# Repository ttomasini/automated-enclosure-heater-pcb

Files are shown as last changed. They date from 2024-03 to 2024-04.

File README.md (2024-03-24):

# Automated Heating System PCB for the Original Prusa Enclosure

## Introduction
This repo contains a PCB implementation of the Automated Heating System control unit for the Original Prusa Enclosure.

Find the schematics [here](doc/schematic.pdf).

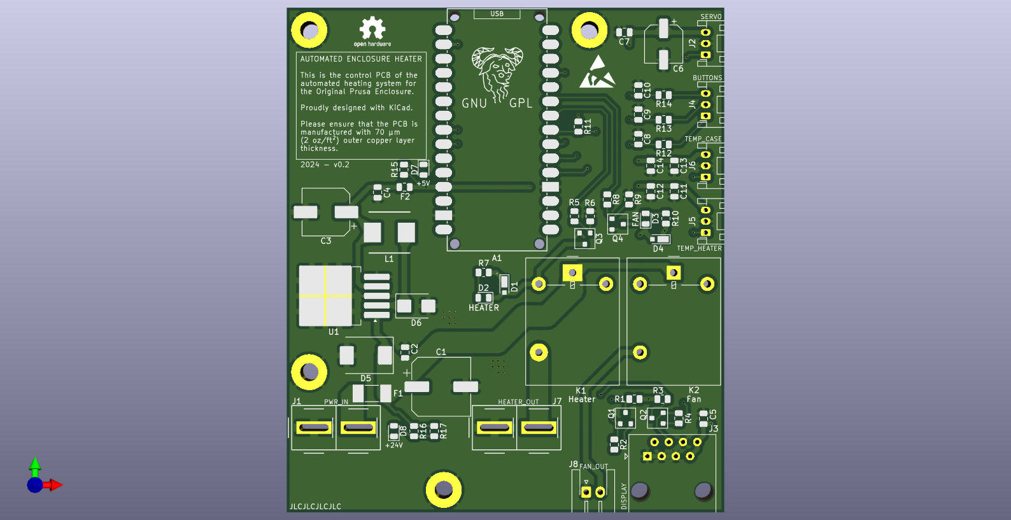
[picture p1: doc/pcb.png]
PCB

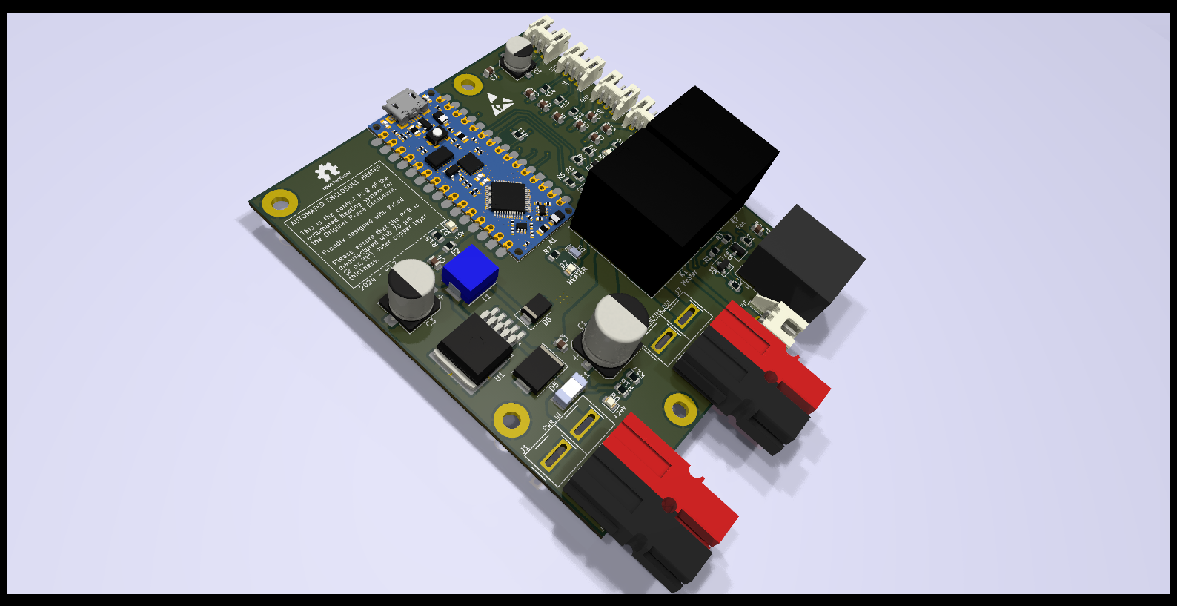
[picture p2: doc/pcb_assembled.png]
PCB assembled


## Manufacturing
Please ensure that the PCB is manufactured with 70 μm (2 oz/ft²) outer copper layer thickness.

## Credits
The original idea and the base principle of the schematic have been designed and published by Lars Knust ([@LarsKnust at Github](https://github.com/LarsKnust) / [@lars at printables.com](https://www.printables.com/@lars)).

Link to the model on Printables: https://www.printables.com/model/561491

This PCB has been proudly designed with KiCad.

## License
This repository is licensed under the GNU General Public License, Version 3. See [the LICENSE file](LICENSE) for more information.

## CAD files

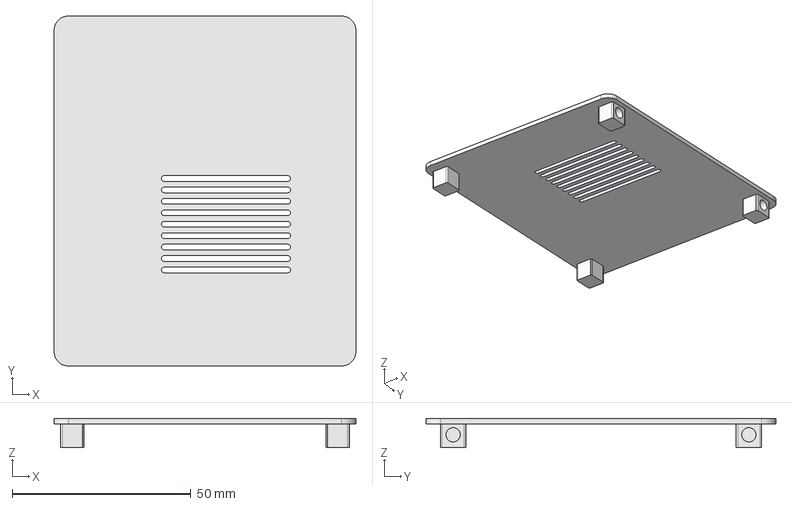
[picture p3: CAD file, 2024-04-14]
Case/Case-Lid.step
84.5 x 98.0 x 8.20 mm

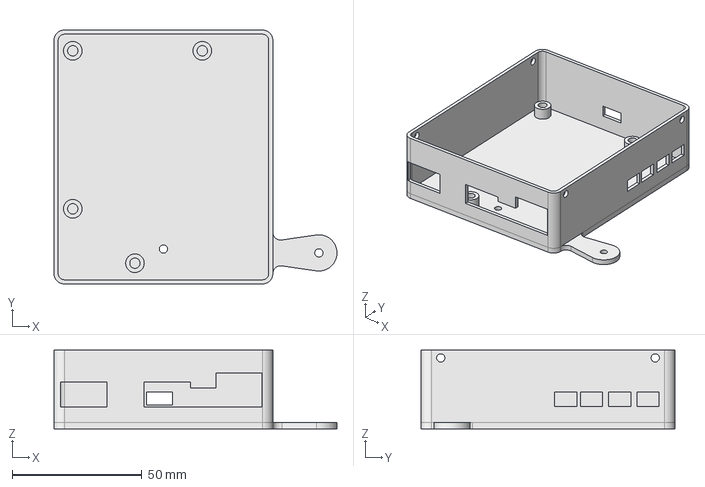
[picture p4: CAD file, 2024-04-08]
Case/Case-Body.step
109.2 x 98.0 x 30.4 mm

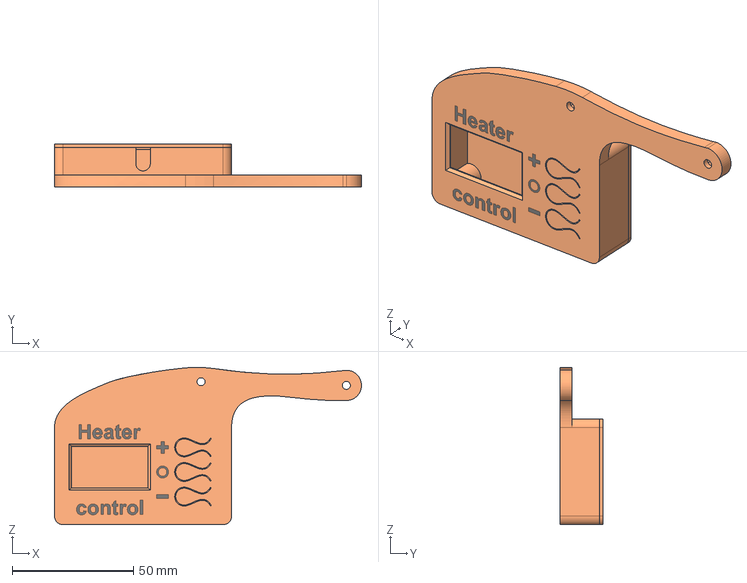
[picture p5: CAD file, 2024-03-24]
Case/Display_Case.step
126.8 x 17.8 x 65.0 mm

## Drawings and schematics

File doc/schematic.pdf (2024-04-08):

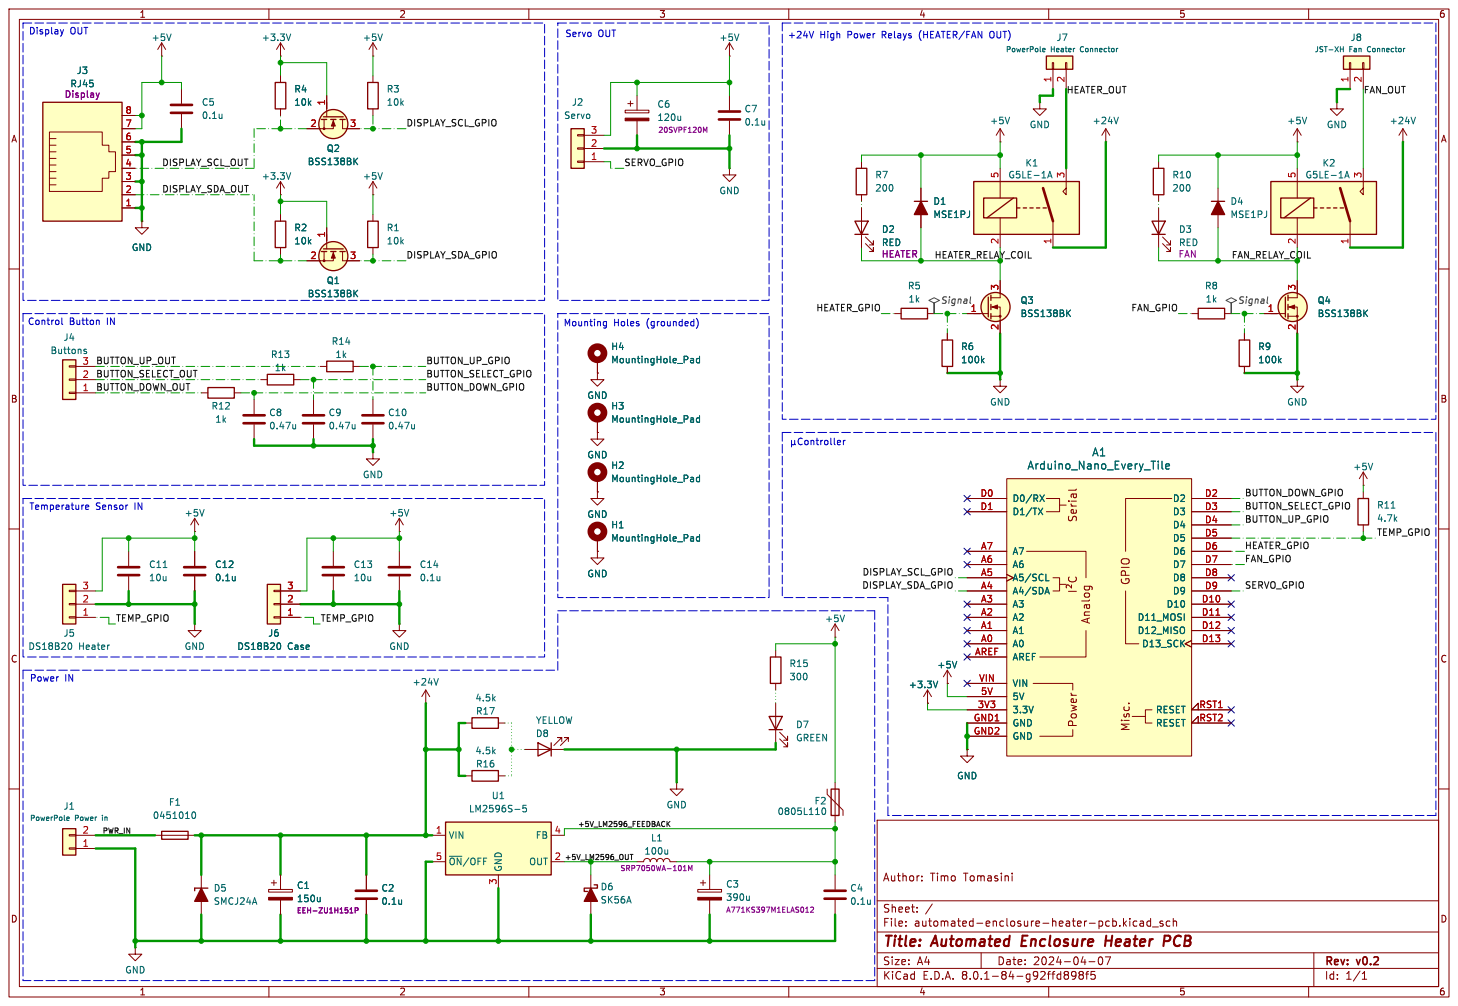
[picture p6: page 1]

Servo OUT Control Button IN

+24V High Power Relays (HEATER/FAN OUT)
J2 Servo R16

JST-XH Fan Connector 1

File: automated-enclosure-heater-pcb.kicad_sch Sheet: / Author: Timo Tomasini
Id: 1/1 Title: Automated Enclosure Heater PCB

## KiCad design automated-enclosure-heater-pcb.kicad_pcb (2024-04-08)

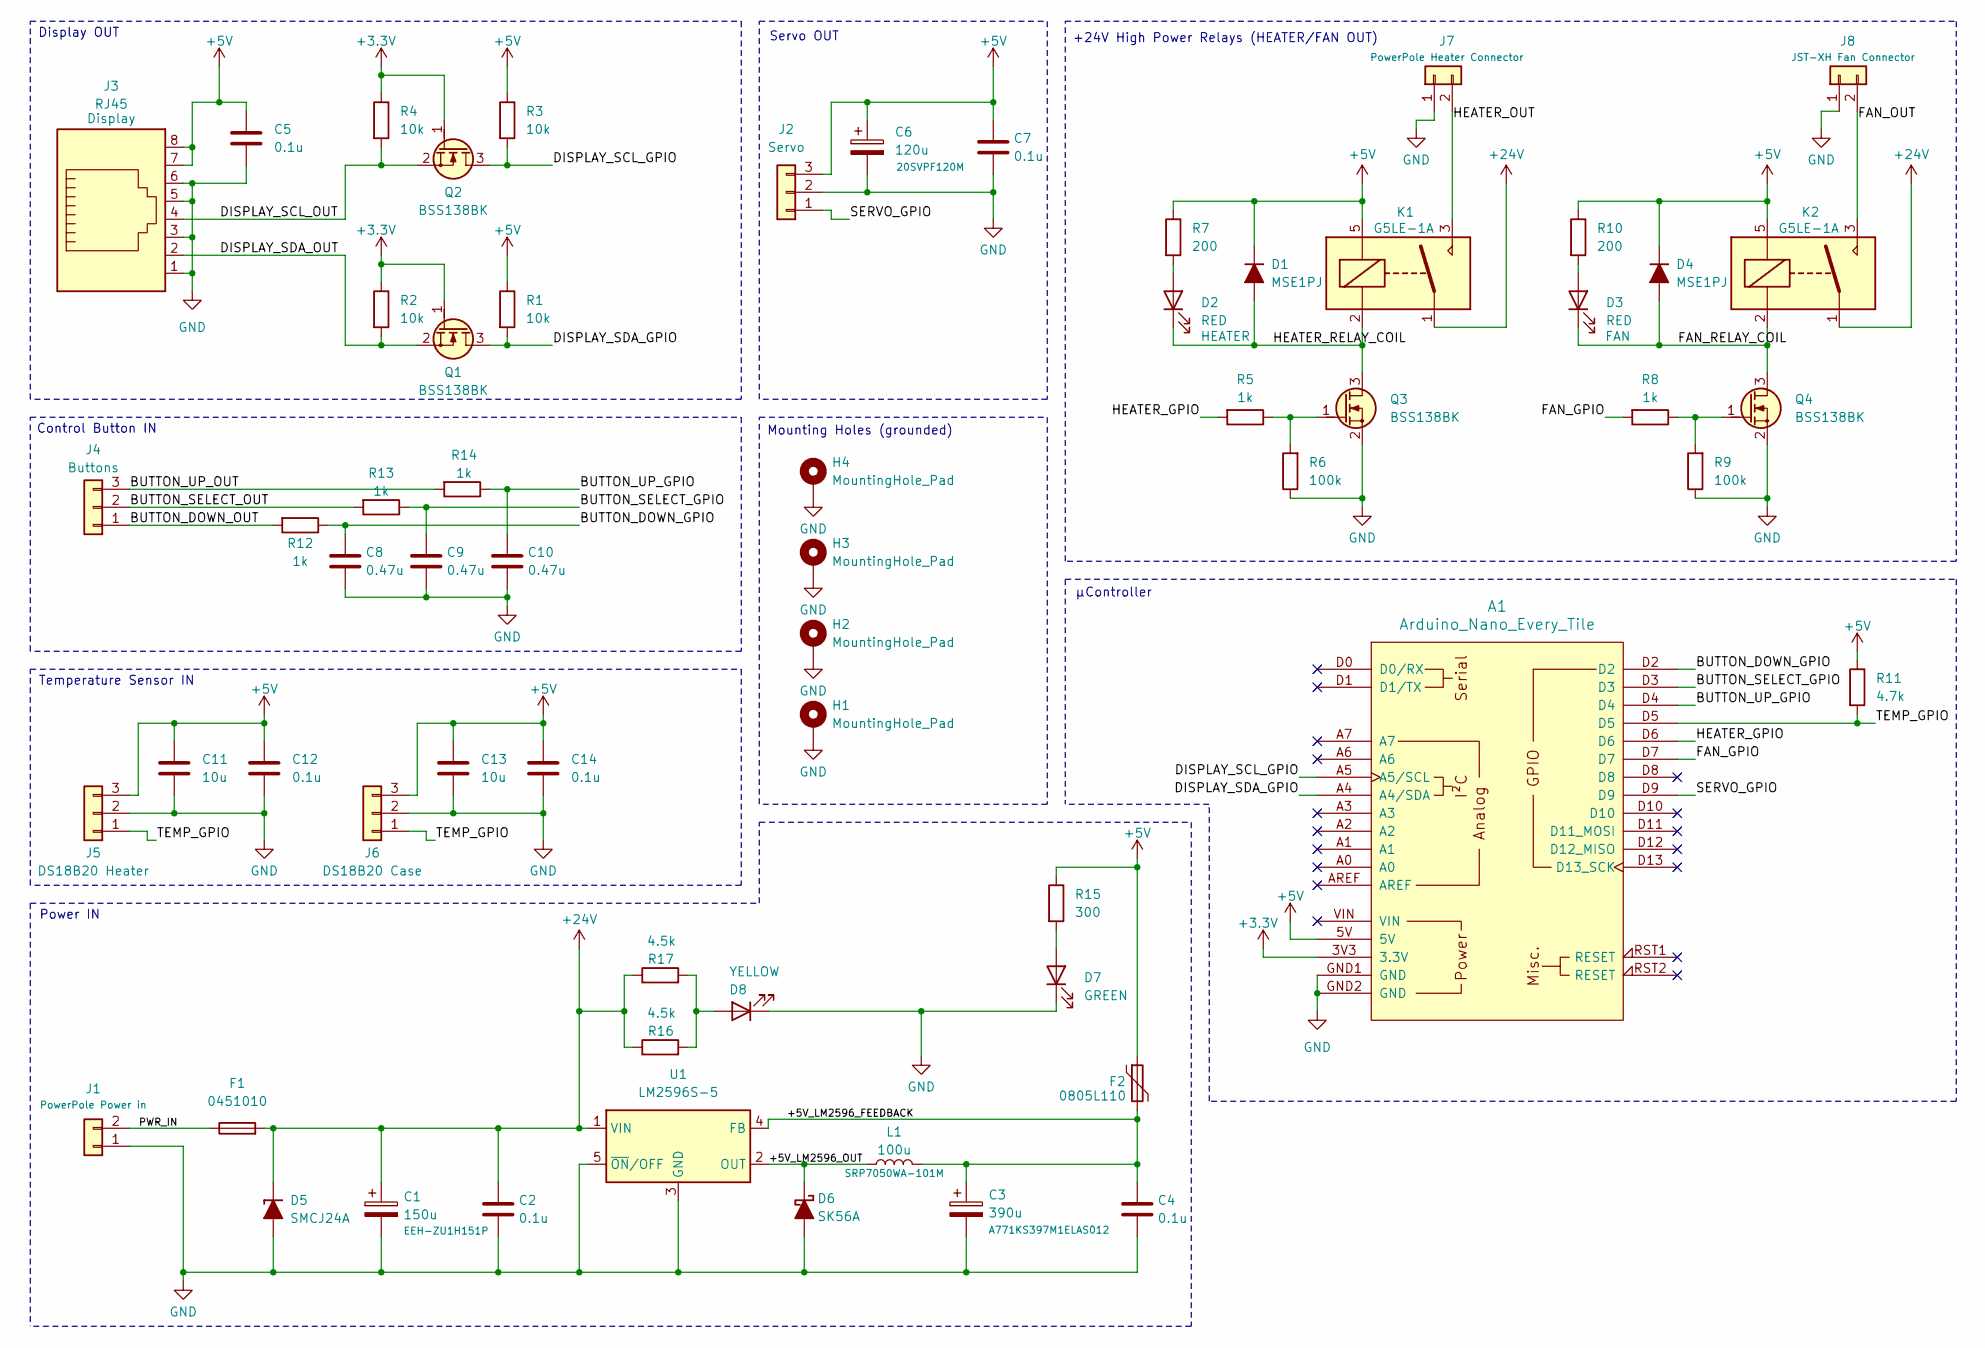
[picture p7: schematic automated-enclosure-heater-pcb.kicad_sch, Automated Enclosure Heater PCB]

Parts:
A1: Arduino_Nano_Every_Tile
C1: 150u; CP_Elec_10x12.6; Part Number EEH-ZU1H151P
C2, C4, C5, C7, C12, C14: 0.1u; C_0805_2012Metric
C3: 390u; CP_Elec_8x12.2_KEMET; Part Number A771KS397M1ELAS012
C6: 120u; CP_Elec_6.3x5.9; Part Number 20SVPF120M
C8, C9, C10: 0.47u; C_0805_2012Metric
C11, C13: 10u; C_0805_2012Metric
D1, D4: MSE1PJ; D_MicroSMP_AK
D2, D3: RED; LED_0805_2012Metric
D5: SMCJ24A; D_SMC
D6: SK56A; D_SMB
D7: GREEN; LED_0805_2012Metric
D8: YELLOW; LED_0805_2012Metric
F1: 0451010; Fuse_Littelfuse-NANO2-451_453
F2: 0805L110; Fuse_0805_2012Metric
H1, H2, H3, H4: MountingHole_Pad; MountingHole_3.2mm_M3_Pad_TopOnly
J1: PowerPole Power in; Anderson_PowerPole_25A_Right_Angle_Pair
J2: Servo; JST_PH_S3B-PH-K_1x03_P2.00mm_Horizontal
J3: RJ45; RJ45_Amphenol_54602-x08_Horizontal
J4: Buttons; JST_PH_S3B-PH-K_1x03_P2.00mm_Horizontal
J5: DS18B20 Heater; JST_PH_S3B-PH-K_1x03_P2.00mm_Horizontal
J6: DS18B20 Case; JST_PH_S3B-PH-K_1x03_P2.00mm_Horizontal
J7: PowerPole Heater Connector; Anderson_PowerPole_25A_Right_Angle_Pair
J8: JST-XH Fan Connector; JST_XH_S2B-XH-A-1_1x02_P2.50mm_Horizontal
K1, K2: G5LE-1A; Relay_SPST_NO_Omron-G5LE-1A
L1: 100u; L_Bourns_SRP7050WA_Series
Q1, Q2, Q3, Q4: BSS138BK; SOT-23
R1, R2, R3, R4: 10k; R_0805_2012Metric
R5, R8, R12, R13, R14: 1k; R_0805_2012Metric
R6, R9: 100k; R_0805_2012Metric
R7, R10: 200; R_0805_2012Metric
R11: 4.7k; R_0805_2012Metric
R15: 300; R_0805_2012Metric
R16, R17: 4.5k; R_0805_2012Metric
U1: LM2596S-5; TO-263-5_TabPin3

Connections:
+3.3V: A1.3V3 (3.3V), Q1.1 (G), Q2.1 (G), R2.1, R4.1
+5V: A1.5V, C5.1, C6.1, C7.1, C11.1, C12.1, C13.1, C14.1, D1.1 (K), D4.1 (K), F2.1, J2.3, J3.7, J3.8, J5.3, J6.3, K1.5, K2.5, R1.1, R3.1, R7.1, R10.1, R11.1, R15.1
+24V: C1.1, C2.1, D5.1 (K), F1.2, K1.1, K2.1, R16.1, R17.1, U1.1 (VIN)
/+5V_LM2596_FEEDBACK: C3.1, C4.1, F2.2, L1.2, U1.4 (FB)
/+5V_LM2596_OUT: D6.1 (K), L1.1, U1.2 (OUT)
/BUTTON_DOWN_GPIO: A1.D2, C8.1, R12.1
/BUTTON_DOWN_OUT: J4.1, R12.2
/BUTTON_SELECT_GPIO: A1.D3, C9.1, R13.1
/BUTTON_SELECT_OUT: J4.2, R13.2
/BUTTON_UP_GPIO: A1.D4, C10.1, R14.1
/BUTTON_UP_OUT: J4.3, R14.2
/DISPLAY_SCL_GPIO: A1.A5 (A5/SCL), Q2.3 (D), R3.2
/DISPLAY_SCL_OUT: J3.4, Q2.2 (S), R4.2
/DISPLAY_SDA_GPIO: A1.A4 (A4/SDA), Q1.3 (D), R1.2
/DISPLAY_SDA_OUT: J3.2, Q1.2 (S), R2.2
/FAN_GPIO: A1.D7, R8.2
/FAN_OUT: J8.2, K2.3
/FAN_RELAY_COIL: D3.1 (K), D4.2 (A), K2.2, Q4.3 (D)
/HEATER_GPIO: A1.D6, R5.2
/HEATER_OUT: J7.2, K1.3
/HEATER_RELAY_COIL: D1.2 (A), D2.1 (K), K1.2, Q3.3 (D)
/PWR_IN: F1.1, J1.2
/SERVO_GPIO: A1.D9, J2.1
/TEMP_GPIO: A1.D5, J5.1, J6.1, R11.2
GND: A1.GND1 (GND), A1.GND2 (GND), C1.2, C2.2, C3.2, C4.2, C5.2, C6.2, C7.2, C8.2, C9.2, C10.2, C11.2, C12.2, C13.2, C14.2, D5.2 (A), D6.2 (A), D7.1 (K), D8.1 (K), H1.1, H2.1, H3.1, H4.1, J1.1, J2.2, J3.1, J3.3, J3.5, J3.6, J5.2, J6.2, J7.1, J8.1, Q3.2 (S), Q4.2 (S), R6.1, R9.1, U1.3 (GND), U1.5 (~ON/OFF)
unnamed: D2.2 (A), R7.2
unnamed: D3.2 (A), R10.2
unnamed: D7.2 (A), R15.2
unnamed: D8.2 (A), R16.2, R17.2
unnamed: Q3.1 (G), R5.1, R6.2
unnamed: Q4.1 (G), R8.1, R9.2

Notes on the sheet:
Servo OUT
Power IN
Temperature Sensor IN
µController
+24V High Power Relays (HEATER/FAN OUT)
Mounting Holes (grounded)
Control Button IN
Display OUT

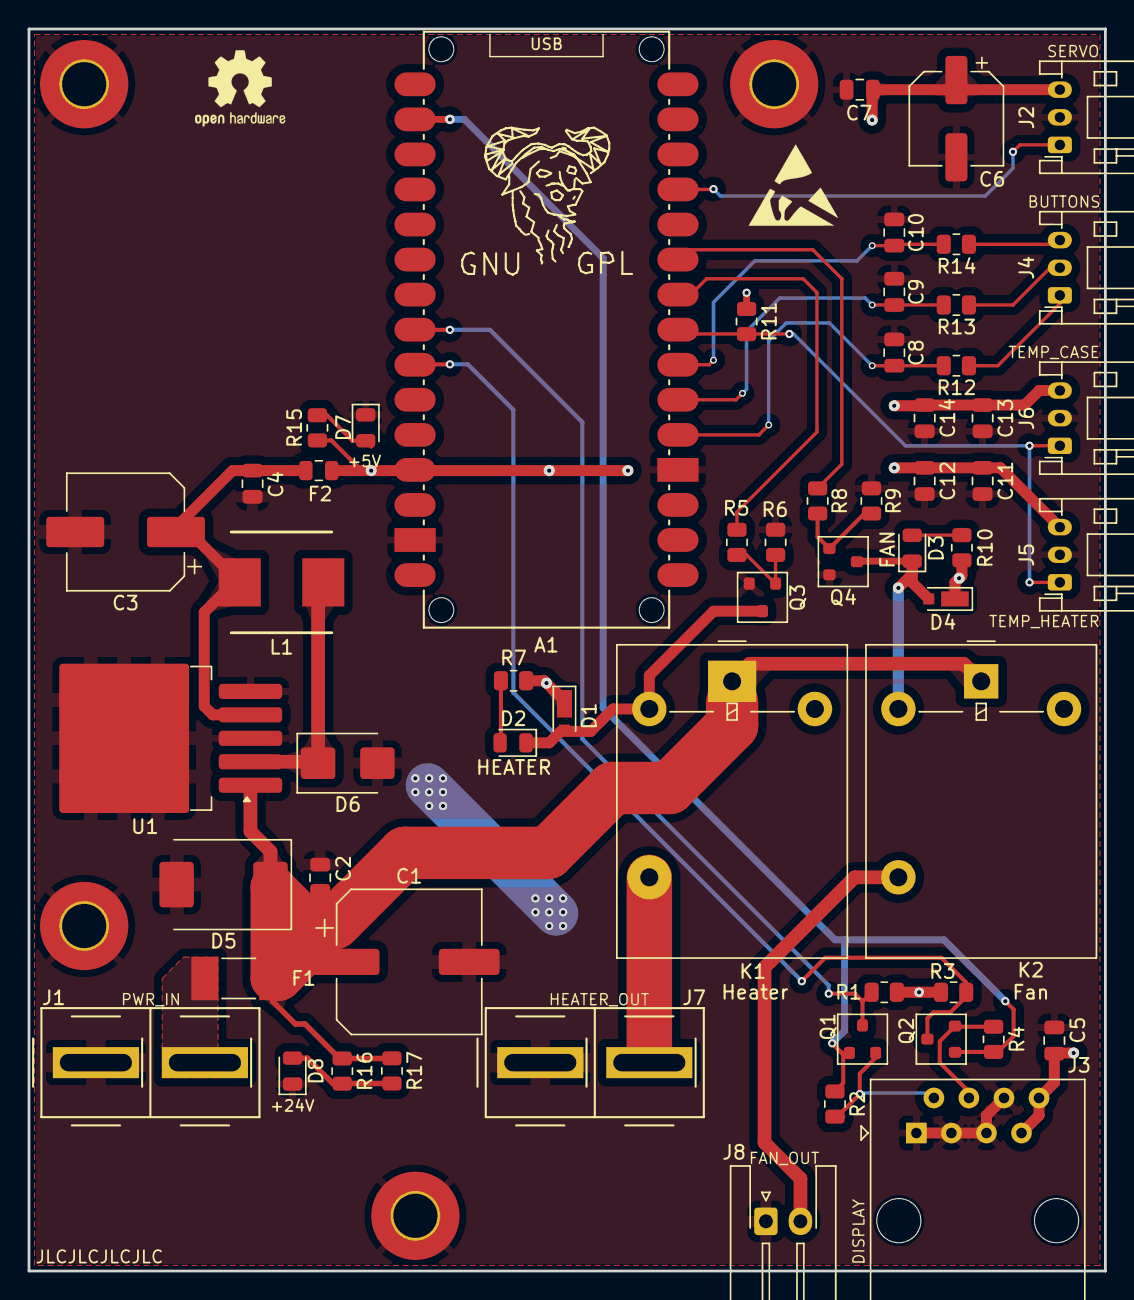
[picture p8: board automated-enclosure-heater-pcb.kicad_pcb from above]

Board: 2 copper layers, 78.0 x 90.0 mm, 62 parts (0 on the bottom side), 31 nets.

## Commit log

2024-03-24 Add schematic and pictures to README.
    [automated-enclosure-heater-pcb.kicad_sch]
2024-03-30 Add fitting 3d printed case made with freecad
    [Case-Body.step, Case-Lid.step]
2024-04-03 Fix LED issue
    [automated-enclosure-heater-pcb.kicad_pcb, automated-enclosure-heater-pcb.kicad_sch]
2024-04-03 Add minor silkscreen adjustments
    [automated-enclosure-heater-pcb.kicad_pcb, automated-enclosure-heater-pcb.kicad_sch]
2024-04-05 Fix DISP pinout
    [automated-enclosure-heater-pcb.kicad_pcb, automated-enclosure-heater-pcb.kicad_sch]
2024-04-07 Adjust Arduino pinout and push version to v0.2
    [automated-enclosure-heater-pcb.kicad_pcb, automated-enclosure-heater-pcb.kicad_sch]
2024-04-08 Add additional case lid screw holes
    [Case-Body.step, Case-Lid.step]
2024-04-08 Add second resistor for 24V LED and adjust power plane size
    [automated-enclosure-heater-pcb.kicad_pcb, automated-enclosure-heater-pcb.kicad_sch]
2024-04-14 Improve heat dissipation and lid fastening
    [Case-Lid.step]
